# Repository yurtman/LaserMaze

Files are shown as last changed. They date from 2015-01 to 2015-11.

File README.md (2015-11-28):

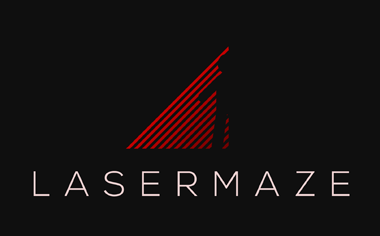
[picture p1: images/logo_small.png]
Header


LaserMaze is an exciting game that imitates the comically bad kind of laser security system found in heist movies. Using Arduino, augmented laser pointers, and a smoke machine, LaserMaze can transform any shipping container or hallway into a practice course for aspiring special agents.

It is currently still very much a prototype and the documentation of the project reflects this. For the most up to date documentation please see the [wiki](https://github.com/yurtman/LaserMaze/wiki).

##Features
- Made with easy to source components (laserpointers, basic electronics)
- Entrance/exit portal to start and stop the timer
- Auto calibration
- Steal detection (item to be stolen can be easily customised)
- Alarm sequence
- Open source

###Not yet implemented but being worked on:
- GUI to display high scores and alignment status (done in the processing language)
- scaling to the arduino Mega to include more lasers
- LED alarm lights integrated with the hardware and code
- sound effects and speaker (Alarm, Maze Active, enter the maze)
- expanding the current positioning strategies
- wireless communication and battery modules

###Abandoned goals:
- videofeed so attendant doens't need to stand inside the smoke filled container the whole day (IR light is also blocked by smoke... duh!)
- moving lasers (nice in the movies, very hard to actually make)

##Examples of use
The LaserMaze started as a hobby project with humble beginnings- a rats nest of alligator clips. 
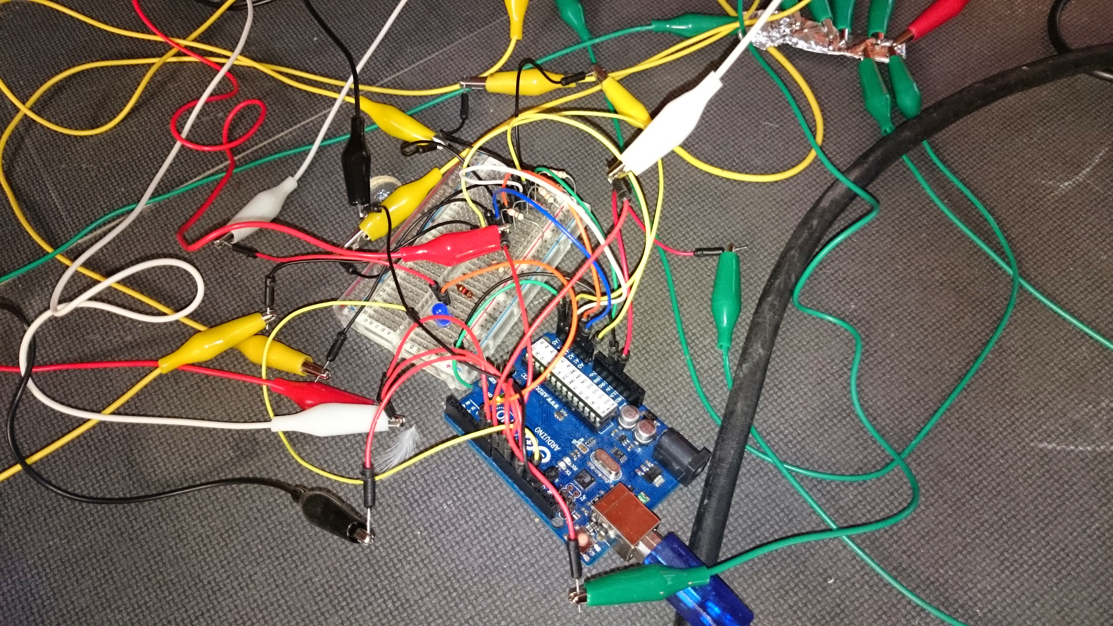
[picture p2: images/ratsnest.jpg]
ratsnest

Since then development has not improved much but the experience resonates well with audiences of all ages and the prototype has already been used for quite a few events:
####Orbit Festival (21st Dec 2014)
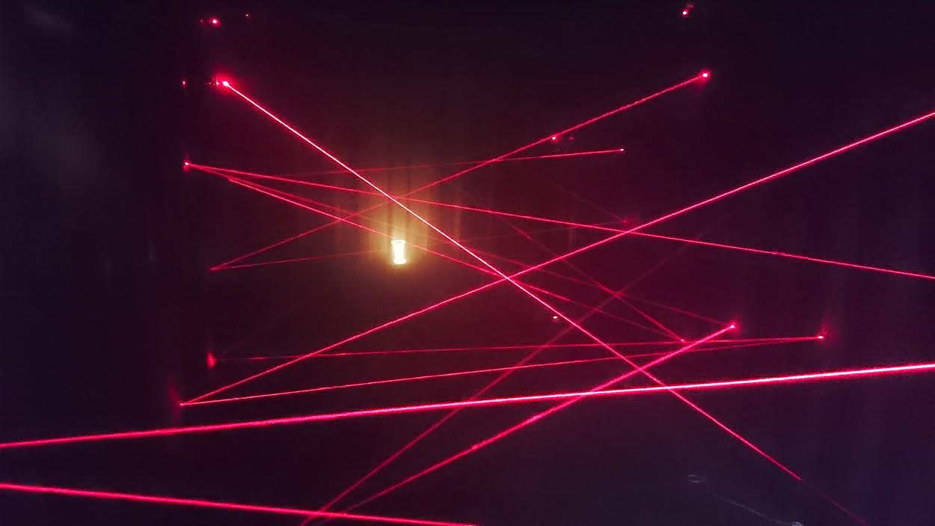
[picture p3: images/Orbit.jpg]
Orbit

####Open day De Jonge Onderzoekers (14th Feb 2015)
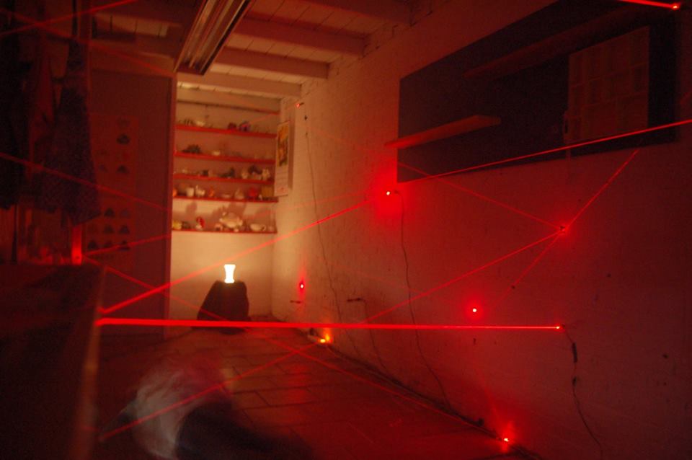
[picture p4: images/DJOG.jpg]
DJOG

####Maak Festival Groningen (12th Apr 2015)
MAAK
####Night of Art and Science (5th Jun 2015)
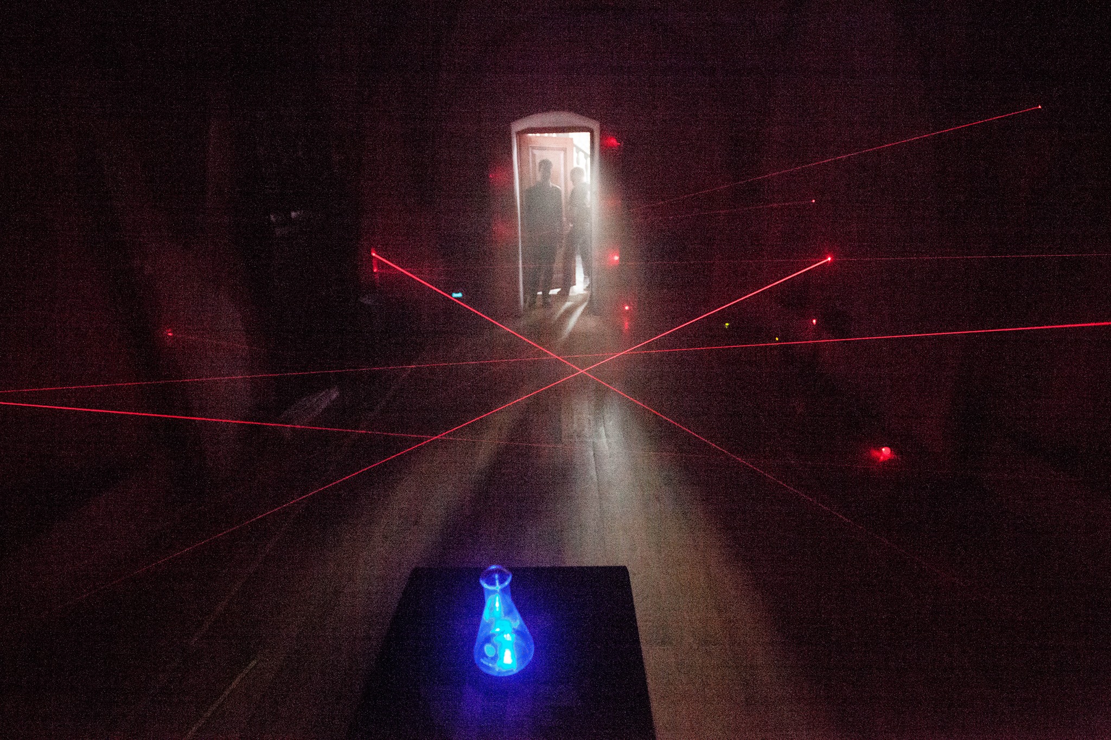
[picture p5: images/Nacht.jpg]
Nacht

####Noorderzon Festival (26th-30th Aug 2015)
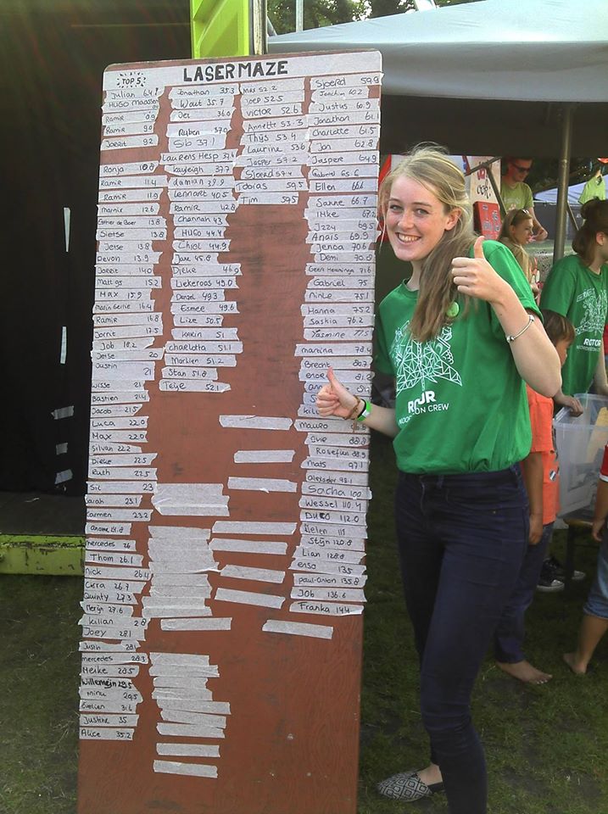
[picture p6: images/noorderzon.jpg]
Noorderzon

####Kinderboekenweek (10th Oct 2015)
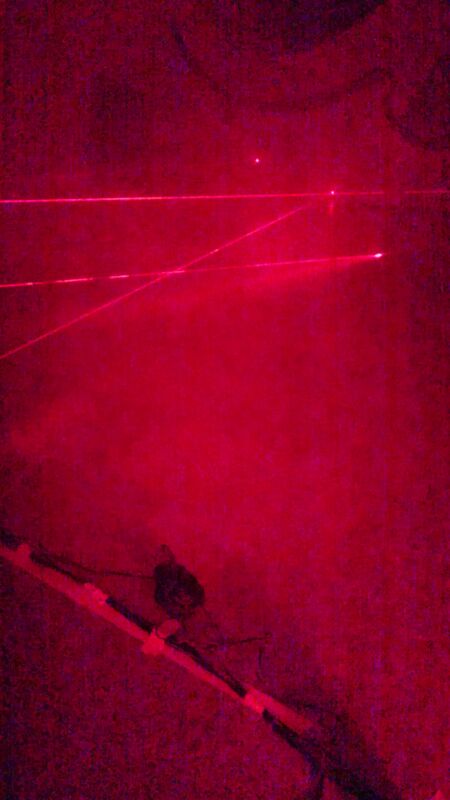
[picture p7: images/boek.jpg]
Kinderboekenweek


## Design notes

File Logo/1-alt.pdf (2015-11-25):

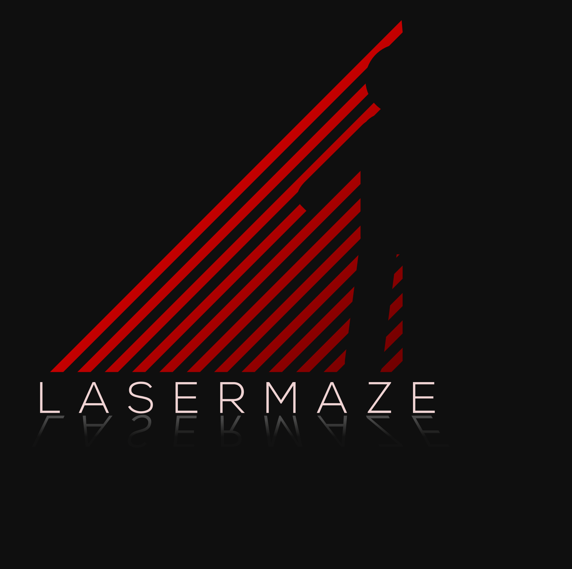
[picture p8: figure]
LASERMAZE

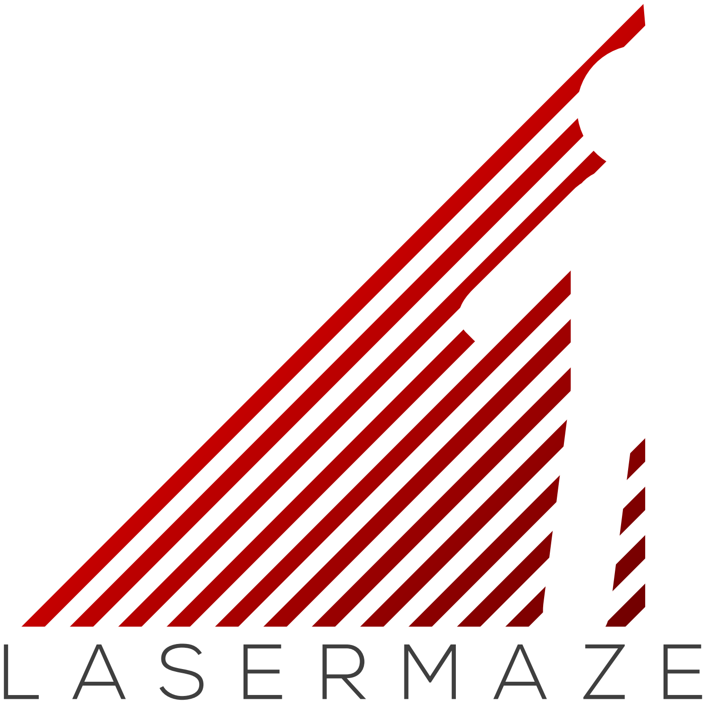
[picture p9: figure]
LASERMAZE

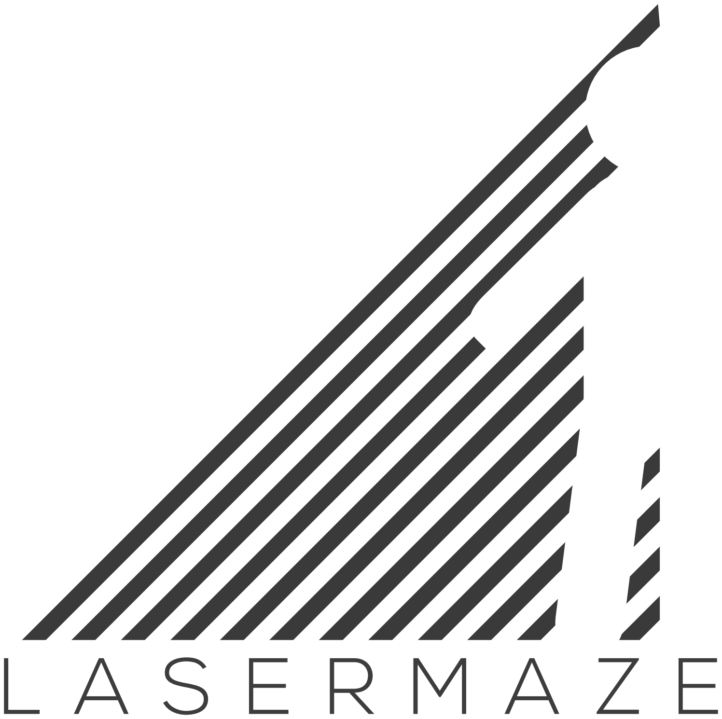
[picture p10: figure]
LASERMAZE

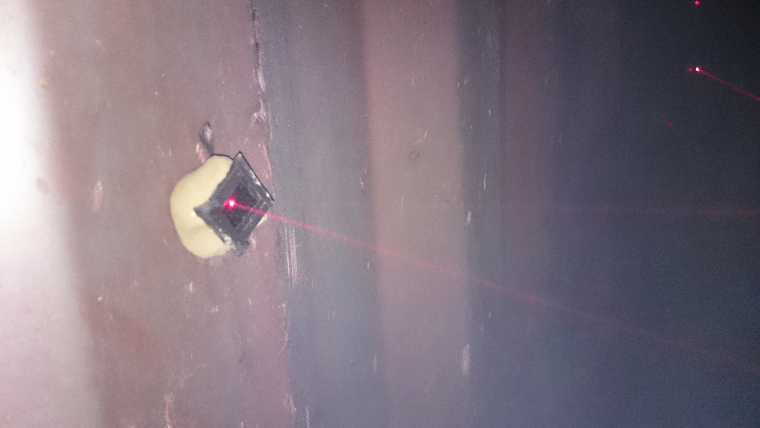
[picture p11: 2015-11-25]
images/mirror.jpg

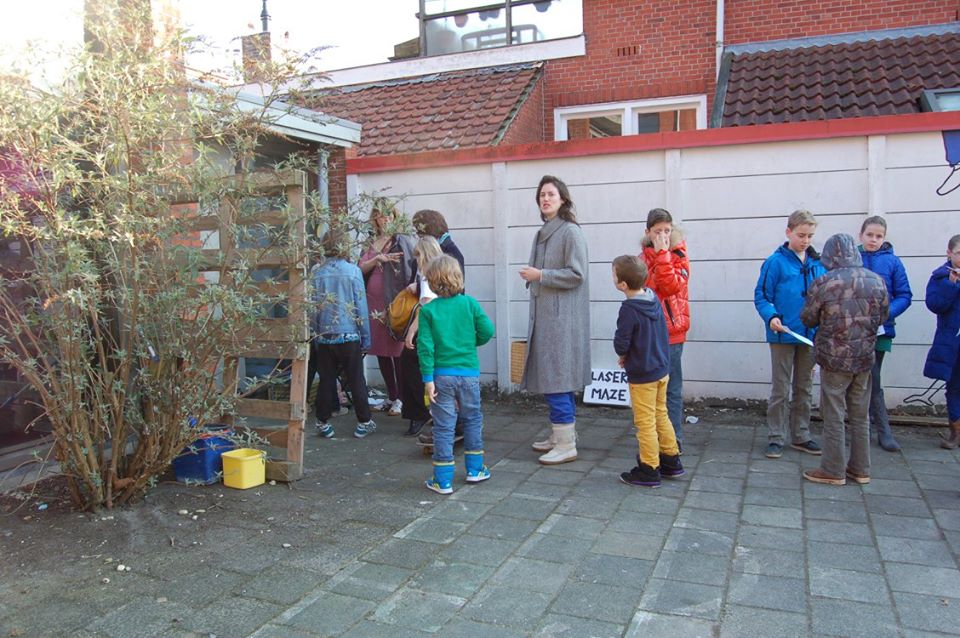
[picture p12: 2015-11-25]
images/Open dag DJO.jpg

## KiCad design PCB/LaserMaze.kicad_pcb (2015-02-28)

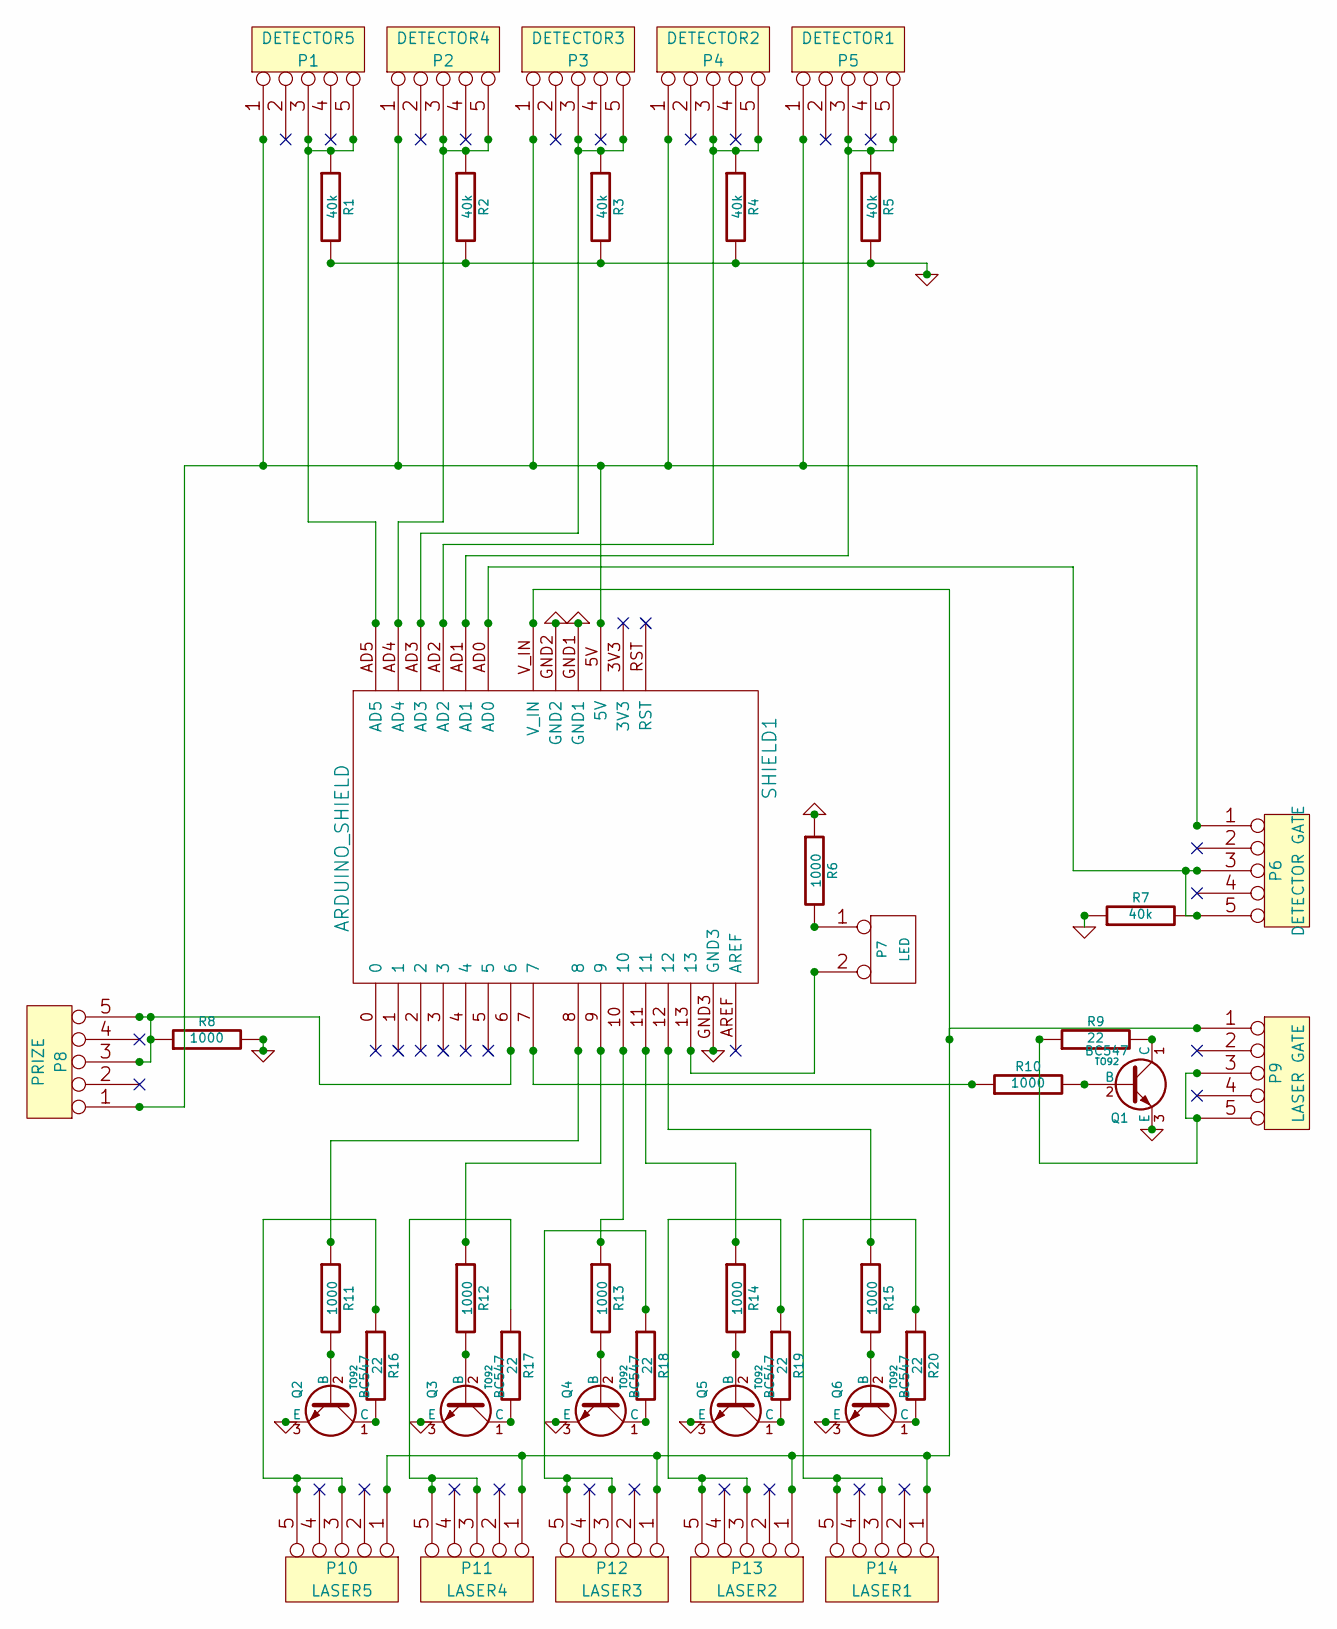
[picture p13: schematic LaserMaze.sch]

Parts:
P1: DETECTOR5
P2: DETECTOR4
P3: DETECTOR3
P4: DETECTOR2
P5: DETECTOR1
P6: DETECTOR GATE
P7: LED
P8: PRIZE
P9: LASER GATE
P10: LASER5
P11: LASER4
P12: LASER3
P13: LASER2
P14: LASER1
Q1, Q2, Q3, Q4, Q5, Q6: BC547; TO92
R1, R2, R3, R4, R5, R7: 40k
R6, R8, R10, R11, R12, R13, R14, R15: 1000
R9, R16, R17, R18, R19, R20: 22
SHIELD1: ARDUINO_SHIELD

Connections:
GND: Q1.3 (E), Q2.3 (E), Q3.3 (E), Q4.3 (E), Q5.3 (E), Q6.3 (E), R1.2, R2.2, R3.2, R4.2, R5.2, R6.1, R7.1, R8.2, SHIELD1.GND1, SHIELD1.GND2, SHIELD1.GND3
unnamed: P9.1, P10.1, P11.1, P12.1, P13.1, P14.1, SHIELD1.V_IN
unnamed: P7.2 (PM), SHIELD1.13
unnamed: R15.1, SHIELD1.12
unnamed: R14.1, SHIELD1.11
unnamed: P1.1, P2.1, P3.1, P4.1, P5.1, P6.1, P8.1, SHIELD1.5V
unnamed: P9.3, P9.5, R9.1
unnamed: R13.1, SHIELD1.10
unnamed: R12.1, SHIELD1.9
unnamed: R11.1, SHIELD1.8
unnamed: R10.1, SHIELD1.7
unnamed: P6.3, P6.5, R7.2, SHIELD1.AD0
unnamed: Q3.2 (B), R12.2
unnamed: Q1.2 (B), R10.2
unnamed: Q1.1 (C), R9.2
unnamed: Q6.2 (B), R15.2
unnamed: Q6.1 (C), R20.2
unnamed: Q5.2 (B), R14.2
unnamed: Q5.1 (C), R19.2
unnamed: Q4.2 (B), R13.2
unnamed: Q4.1 (C), R18.2
unnamed: Q3.1 (C), R17.2
unnamed: Q2.2 (B), R11.2
unnamed: Q2.1 (C), R16.2
unnamed: P1.3, P1.5, R1.1, SHIELD1.AD5
unnamed: P2.3, P2.5, R2.1, SHIELD1.AD4
unnamed: P8.3, P8.5, R8.1, SHIELD1.6
unnamed: P13.3, P13.5, R19.1
unnamed: P12.3, P12.5, R18.1
unnamed: P11.3, P11.5, R17.1
unnamed: P14.3, P14.5, R20.1
unnamed: P10.3, P10.5, R16.1
unnamed: P3.3, P3.5, R3.1, SHIELD1.AD3
unnamed: P4.3, P4.5, R4.1, SHIELD1.AD2
unnamed: P5.3, P5.5, R5.1, SHIELD1.AD1
unnamed: P7.1, R6.2

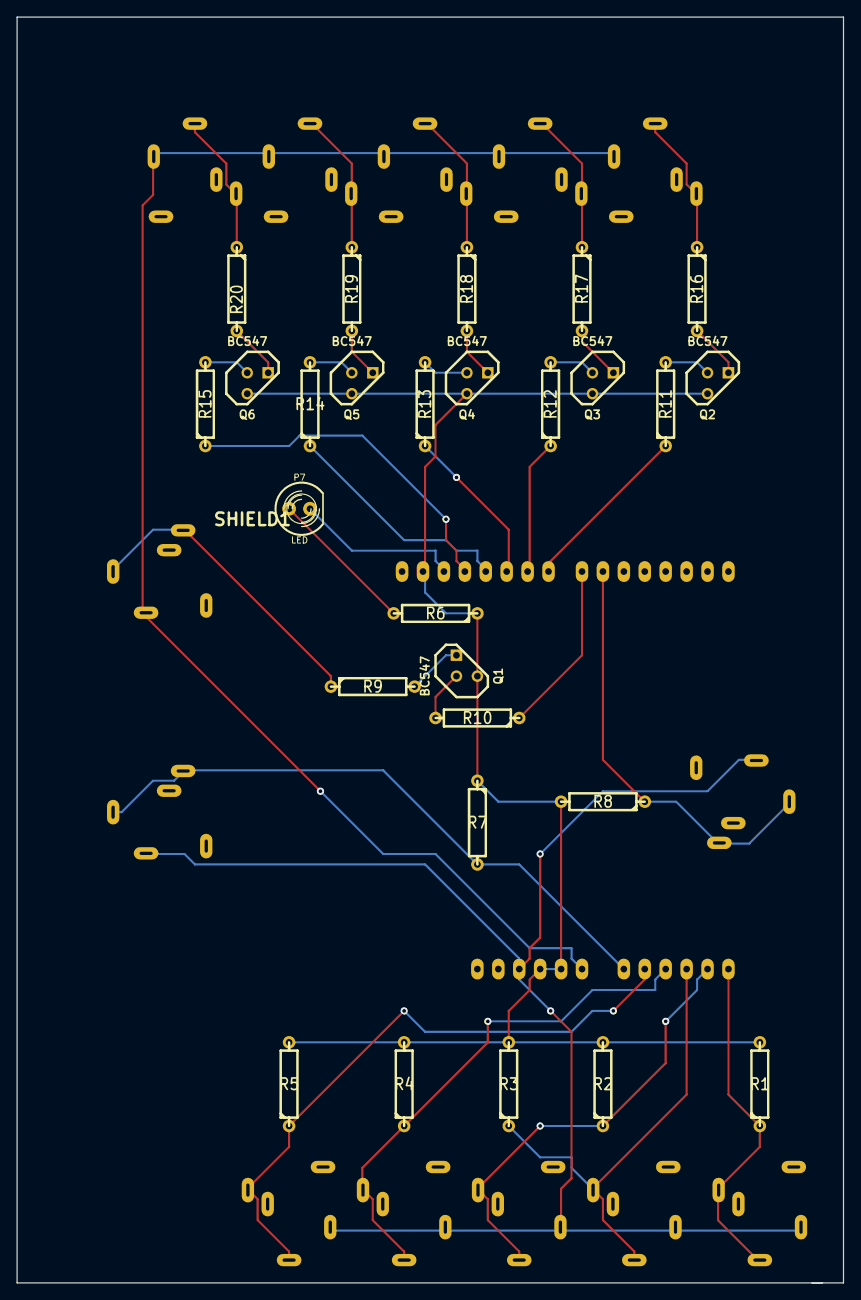
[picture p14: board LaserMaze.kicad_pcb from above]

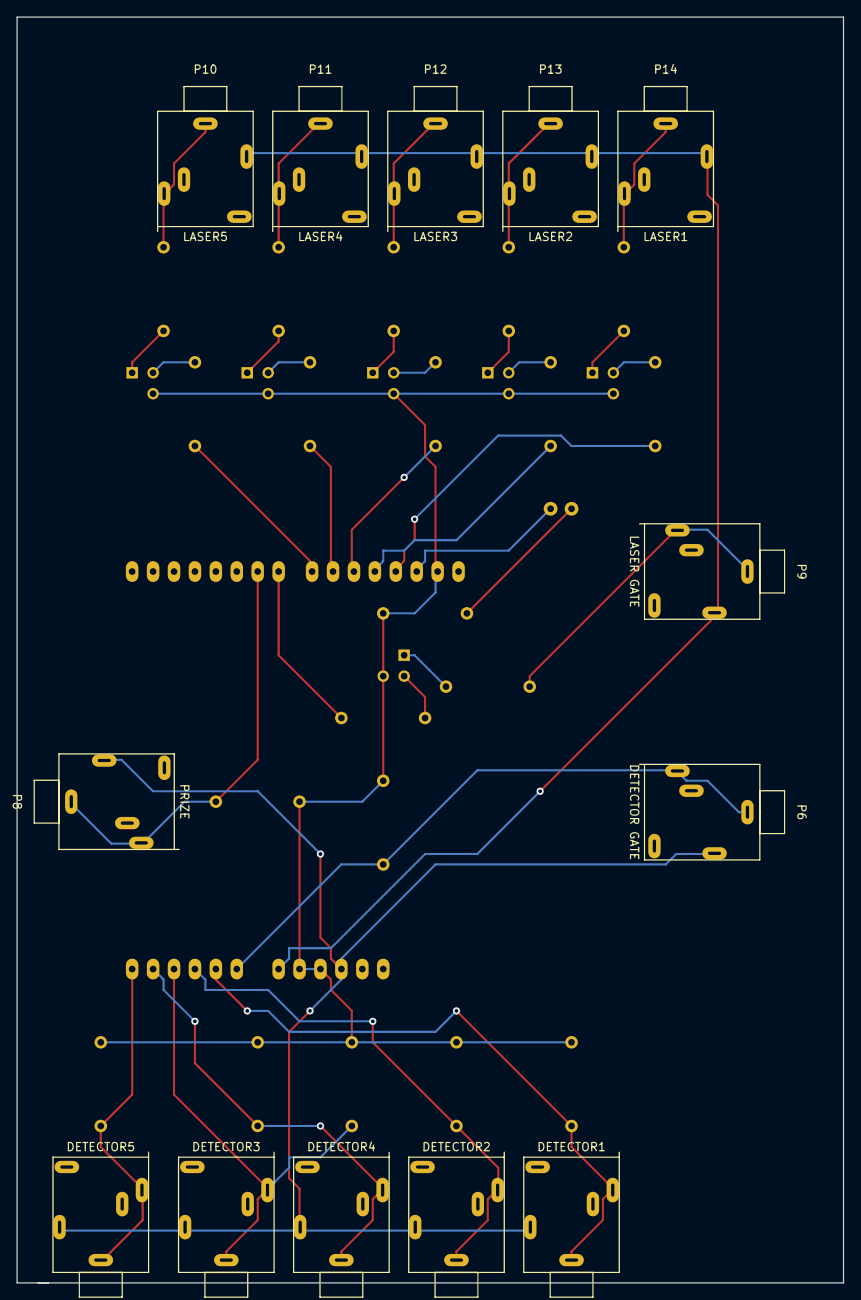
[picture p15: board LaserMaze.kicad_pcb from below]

Board: 2 copper layers, 100.3 x 153.7 mm, 41 parts (13 on the bottom side), 36 nets.

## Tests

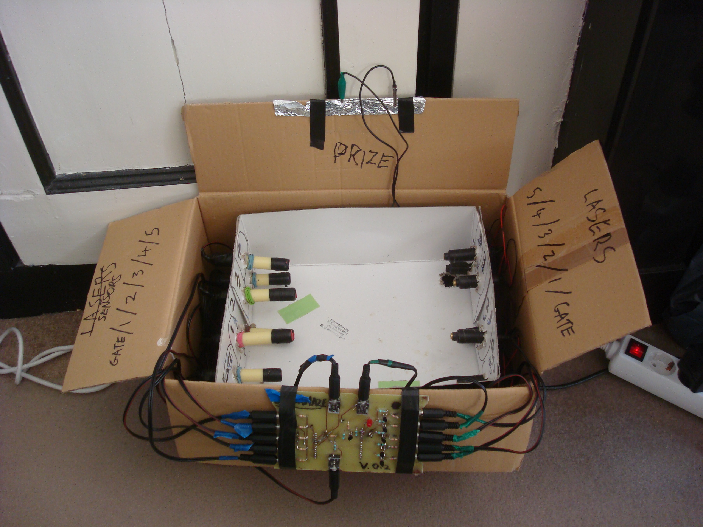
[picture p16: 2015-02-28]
images/testbox.JPG

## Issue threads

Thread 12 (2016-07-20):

Update

designway, 2016-07-20:
Hi,

Do you have any update based on the current lasermaze? And what lasers/sensors are you using?

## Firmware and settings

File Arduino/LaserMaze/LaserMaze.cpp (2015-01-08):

#include "LaserMaze.h"
#include "Arduino.h"

// CONSTRUCTOR
LaserMaze::LaserMaze(
  int alarm,
  int laser1, int laser2, int laser3, int laser4, int laser5,
  int portallaser,  int prize,  int portaldetector,
  int detector1, int detector2, int detector3, int detector4, int detector5
)
{
    Serial.println("LaserMaze::LaserMaze");
    delay(1000);
    pinMode(alarm, OUTPUT);
    m_alarm = alarm;
    pinMode(laser1, OUTPUT);
    m_laser1 = laser1;
	pinMode(laser2, OUTPUT);
    m_laser2 = laser2;
	pinMode(laser3, OUTPUT);
    m_laser3 = laser3;
	pinMode(laser4, OUTPUT);
    m_laser4 = laser4;
	pinMode(laser5, OUTPUT);
    m_laser5 = laser5;
	pinMode(portallaser, OUTPUT);
    m_portallaser = portallaser;
    pinMode(prize, INPUT);
    m_prize = prize;
    m_portaldetector = portaldetector;
    m_detector1 = detector1;
    m_detector2 = detector2;
    m_detector3 = detector3;
    m_detector4 = detector4;
    m_detector5 = detector5;
    Serial.println("An instance of LaserMaze has been created. Use Start() to run.");
} 

// BEGIN
void LaserMaze::Start() {
    AlignMaze();
}

// ALIGN
void LaserMaze::AlignMaze() {
    while (isaligned == false) {
        digitalWrite(m_portallaser, HIGH);
        digitalWrite(m_laser1, HIGH);
        digitalWrite(m_laser2, HIGH);
        digitalWrite(m_laser3, HIGH);
        digitalWrite(m_laser4, HIGH);
        digitalWrite(m_laser5, HIGH);
        Serial.println("Please direct the lasers onto the detectors and put prize in place when done.");
		
		// when alignment is complete
        if (DetectSteal() == true) {
            delay(5000);
            Serial.println("You have indicated that you are done with alignment. The sensors will now be calibrated.");
            digitalWrite(m_portallaser, LOW);
            digitalWrite(m_laser1, LOW);
            digitalWrite(m_laser2, LOW);
            digitalWrite(m_laser3, LOW);
            digitalWrite(m_laser4, LOW);
            digitalWrite(m_laser5, LOW);
      		isaligned = true;           
            CalibrateMaze();
        };
    };
    Serial.println("The Beams are already aligned.");

}

// GET THRESHOLD
int LaserMaze::GetThreshold(const int laser, const int detector) {
    int h1, h2, h3 = 0;
    int l1, l2, l3 = 1;
	const int t = 50;
	
	// find threshold by turning laser on and off 3 times	
	 digitalWrite(laser, HIGH);
	 delay(t);
	 h1 = analogRead(detector);
	 digitalWrite(laser, LOW);
	 delay(t);
	 l1 = analogRead(detector);
	 digitalWrite(laser, HIGH);
	 delay(t);
	 h2 = analogRead(detector);
	 digitalWrite(laser, LOW);
	 delay(t);
	 l2 = analogRead(detector);
	 digitalWrite(laser, HIGH);
	 delay(t);
	 h3 = analogRead(detector);
	 digitalWrite(laser, LOW);
	 delay(t);
	 l3 = analogRead(detector);
		
	 // return the threshold value
	 int minimum = (l1+l2+l3)/3;
	 int maximum =  (h1+h2+h3)/3;
     int range =  maximum - minimum ;
    return minimum + 0.05*range;
}

// GET RANGE
int LaserMaze::GetRange(const int laser, const int detector) {
	int h1, h2, h3 = 0;
	int l1, l2, l3 = 1;
	const int t = 50;
	
	// find range by turning laser on and off 3 times	
	digitalWrite(laser, HIGH);
	delay(t);
	h1 = analogRead(detector);
	digitalWrite(laser, LOW);
	delay(t);
	l1 = analogRead(detector);
	digitalWrite(laser, HIGH);
	delay(t);
	h2 = analogRead(detector);
	digitalWrite(laser, LOW);
	delay(t);
	l2 = analogRead(detector);
	digitalWrite(laser, HIGH);
	delay(t);
	h3 = analogRead(detector);
	digitalWrite(laser, LOW);
	delay(t);
	l3 = analogRead(detector);
	
	// return the range value
	int minimum = (l1+l2+l3)/3;
	int maximum =  (h1+h2+h3)/3;
    return maximum - minimum;
}

// PRINT CALIBRATION VALUES
void LaserMaze::PrintCalibrationValues() {
    Serial.print("Gate Range: \t \t");
    Serial.print(m_portalrange);
    Serial.print("\t Gate Threshold: \t");
    Serial.println(m_portalthreshold);
    Serial.print("Detector 1 Range: \t");
    Serial.print(m_range1);
    Serial.print("\t Detector1 Threshold: \t");
    Serial.println(m_threshold1);
    Serial.print("Detector 2 Range: \t");
    Serial.print(m_range2);
    Serial.print("\t Detector2 Threshold: \t");
    Serial.println(m_threshold2);
    Serial.print("Detector 3 Range: \t");
    Serial.print(m_range3);
    Serial.print("\t Detector3 Threshold: \t");
    Serial.println(m_threshold3);
    Serial.print("Detector 4 Range: \t");
    Serial.print(m_range4);
    Serial.print("\t Detector4 Threshold: \t");
    Serial.println(m_threshold4);
    Serial.print("Detector 5 Range: \t");
    Serial.print(m_range5);
    Serial.print("\t Detector5 Threshold: \t");
    Serial.println(m_threshold5);
}

// CALIBRATE
void LaserMaze::CalibrateMaze() {
    Serial.println("Calibration in progress...   ");
    // store the threshold values of each detector
    m_portalthreshold = GetThreshold(m_portallaser, m_portaldetector);
    m_threshold1 = GetThreshold(m_laser1, m_detector1);
    m_threshold2 = GetThreshold(m_laser2, m_detector2);
    m_threshold3 = GetThreshold(m_laser3, m_detector3);
    m_threshold4 = GetThreshold(m_laser4, m_detector4);
    m_threshold5 = GetThreshold(m_laser5, m_detector5);
    // store the range values of each detector
    m_portalrange = GetRange(m_portallaser, m_portaldetector);
    m_range1 = GetRange(m_laser1, m_detector1);
    m_range2 = GetRange(m_laser2, m_detector2);
    m_range3 = GetRange(m_laser3, m_detector3);
    m_range4 = GetRange(m_laser4, m_detector4);
    m_range5 = GetRange(m_laser5, m_detector5);
    Serial.println("Calibration process completed!");

	// print the thresholds and ranges
    PrintCalibrationValues();
    iscalibrated = true;
    ResetMaze();
}


// RESETMAZE
void LaserMaze::ResetMaze() {
    // make sure prize is in place
    if(digitalRead(m_prize) == LOW) {
        Serial.println("Please put the prize back");
        delay(5000);
    }
    Serial.println("The Maze has been reset!");
	isplaying = false;
	isstealing = false;
    iswinner = false;
    isactive = false;
    CheckAlignment();
	if(isaligned && iscalibrated) {
        ActivateMaze();
    }
    else {
        Serial.println("The game cannot be reset because it is not aligned and calibrated.");
        AlignMaze();
    };
}

// START TIMER
void LaserMaze::TimerStart() {
    m_StartTime =   millis();
}
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

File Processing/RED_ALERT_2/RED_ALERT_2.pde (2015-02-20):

//sketch by Arlette Reneman and Winand Slingenbergh

import ddf.minim.*;

Minim minim;
AudioPlayer player;

void setup()
{
  size(512, 200, P3D);
  
  // we pass this to Minim so that it can load files from the data directory
  minim = new Minim(this);
  
  // loadFile will look in all the same places as loadImage does.
  // this means you can find files that are in the data folder and the 
  // sketch folder. you can also pass an absolute path, or a URL.
  player = minim.loadFile("Alarm.mp3");
  
  // play the file from start to finish.
  // if you want to play the file again, 
  // you need to call rewind() first.
  player.play();
}

void keyPressed() {
 
  if (key == ' ') {
    background(255);
    player = minim.loadFile("James Bond Theme.mp3");
  }
   player.play();
   
   if(key == ENTER) {
     exit();
   }
}
  
void draw()
{
  background(255,0,0);
  stroke(0);
  
  // draw the waveforms
  // the values returned by left.get() and right.get() will be between -1 and 1,
  // so we need to scale them up to see the waveform
  // note that if the file is MONO, left.get() and right.get() will return the same value
  for(int i = 0; i < player.bufferSize() - 1; i++)
  {
    float x1 = map( i, 0, player.bufferSize(), 0, width );
    float x2 = map( i+1, 0, player.bufferSize(), 0, width );
    line( x1, 50 + player.left.get(i)*50, x2, 50 + player.left.get(i+1)*50 );
    line( x1, 150 + player.right.get(i)*50, x2, 150 + player.right.get(i+1)*50 );
  }
}

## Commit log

2015-01-08 First commit, arduino code, processing GUI barebones.
2015-02-28 added some test sketches to the arduino forder, KiCAD design files for the PCB and some images
    [LaserMaze.kicad_pcb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]
2015-09-02 Update README.md
    minor update on the current situation
